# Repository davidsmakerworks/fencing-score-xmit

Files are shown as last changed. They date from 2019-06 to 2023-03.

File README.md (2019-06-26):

# fencing-score-xmit
Remote fencing scoring light display transmitter

This project is used to transmit the display from a fencing scoring machine to up to four remote displays, which could be wall lights or in-mask lights. A fencing scoring machine display consists of four lights from left to right: white, red, green, white. The red light indicates a valid hit by the fencer on the left and the green light indicates a valid hit by the fencer on the right. The corresponding white (or yellow) lights indicate a an off-target hit or equipment malfunction for the fencer on that side.

This was designed to work with a Triplette Club Scoring machine which I reverse engineered to discover the gate on each MOSFET that drives one of the lights. Inputs to the the transmitter module are soldered to the corresponding gate on the MOSFET allowing the signal to be observed without affecting the function of the scoring machine.

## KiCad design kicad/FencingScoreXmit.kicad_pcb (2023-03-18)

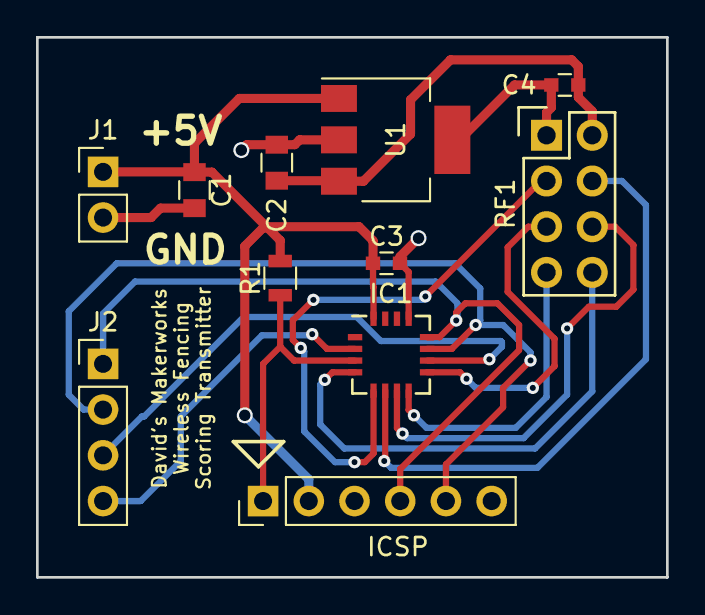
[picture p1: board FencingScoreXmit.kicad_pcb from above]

Board: 2 copper layers, 35.0 x 30.0 mm, 11 parts (0 on the bottom side), 14 nets.

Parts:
C1: 10uF; C_0805
C2: 1uF; C_0805
C3, C4: 0.1uF; C_0603
IC1: PIC16F18323-I/JQ; QFN-16-1EP_4x4mm_Pitch0.65mm
ICSP: ICSP; Pin_Header_Straight_1x06_Pitch2.54mm
J1: PWR_IN; Pin_Header_Straight_1x02_Pitch2.54mm
J2: SCORE_MACH; Pin_Header_Straight_1x04_Pitch2.54mm
R1: 10K; R_0805
RF1: nRF24L01+-MOD; nRF24L01+-Module
U1: MCP1824S33/DB; SOT-223

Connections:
+3V3: C2.1, C4.1, RF1.2, U1.3
+5V: C1.1, C3.1, IC1.16, ICSP.2, J1.1, R1.2, U1.1
GND: C1.2, C2.2, C3.2, C4.2, IC1.13, ICSP.3, J1.2, RF1.1, U1.2, U1.4
unnamed: IC1.2, J2.4
unnamed: IC1.3, ICSP.1, R1.1
unnamed: IC1.4, RF1.8
unnamed: IC1.5, RF1.3
unnamed: IC1.6, RF1.4
unnamed: IC1.7, RF1.6
unnamed: IC1.8, RF1.7
unnamed: IC1.9, RF1.5
unnamed: IC1.10, J2.3
unnamed: IC1.11, ICSP.5, J2.2
unnamed: IC1.12, ICSP.4, J2.1

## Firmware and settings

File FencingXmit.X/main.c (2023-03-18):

/*
 * Remote Fencing Score Display - Transmitter
 * Copyright (c) 2019 David Rice
 *
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
 * Designed for PIC16F18323 or PIC16F18325
 * 
 * Interfaces with nRF24L01+ 2.4 GHz RF module for transmission
 */

// PIC16F18323 Configuration Bit Settings

// 'C' source line config statements

// CONFIG1
#pragma config FEXTOSC = OFF    // FEXTOSC External Oscillator mode Selection bits (Oscillator not enabled)
#pragma config RSTOSC = HFINT1  // Power-up default value for COSC bits (HFINTOSC (1MHz))
#pragma config CLKOUTEN = OFF   // Clock Out Enable bit (CLKOUT function is disabled; I/O or oscillator function on OSC2)
#pragma config CSWEN = ON       // Clock Switch Enable bit (Writing to NOSC and NDIV is allowed)
#pragma config FCMEN = OFF      // Fail-Safe Clock Monitor Enable (Fail-Safe Clock Monitor is disabled)

// CONFIG2
#pragma config MCLRE = ON       // Master Clear Enable bit (MCLR/VPP pin function is MCLR; Weak pull-up enabled)
#pragma config PWRTE = ON       // Power-up Timer Enable bit (PWRT enabled)
#pragma config WDTE = OFF       // Watchdog Timer Enable bits (WDT disabled; SWDTEN is ignored)
#pragma config LPBOREN = OFF    // Low-power BOR enable bit (ULPBOR disabled)
#pragma config BOREN = ON       // Brown-out Reset Enable bits (Brown-out Reset enabled, SBOREN bit ignored)
#pragma config BORV = LOW       // Brown-out Reset Voltage selection bit (Brown-out voltage (Vbor) set to 2.45V)
#pragma config PPS1WAY = ON     // PPSLOCK bit One-Way Set Enable bit (The PPSLOCK bit can be cleared and set only once; PPS registers remain locked after one clear/set cycle)
#pragma config STVREN = ON      // Stack Overflow/Underflow Reset Enable bit (Stack Overflow or Underflow will cause a Reset)
#pragma config DEBUG = OFF      // Debugger enable bit (Background debugger disabled)

// CONFIG3
#pragma config WRT = OFF        // User NVM self-write protection bits (Write protection off)
#pragma config LVP = ON         // Low Voltage Programming Enable bit (Low Voltage programming enabled. MCLR/VPP pin function is MCLR. MCLRE configuration bit is ignored.)

// CONFIG4
#pragma config CP = OFF         // User NVM Program Memory Code Protection bit (User NVM code protection disabled)
#pragma config CPD = OFF        // Data NVM Memory Code Protection bit (Data NVM code protection disabled)

// #pragma config statements should precede project file includes.
// Use project enums instead of #define for ON and OFF.

#include <xc.h>
#include <stdint.h>
#include <stdbool.h>

#include "nRF24L01P.h"
#include "nRF24L01P-cfg.h"

/* CONFIGURABLE OPTIONS START HERE */
#define RF_CHANNEL      0x0CU
/* CONFIGURABLE OPTIONS END HERE */

#define _XTAL_FREQ      4000000

#define ADDR_LEN        5
#define PAYLOAD_WIDTH   1

#define LEFT_RED_MASK       0b00110000
#define RIGHT_GREEN_MASK    0b00001100
#define LEFT_WHITE_MASK     0b11000000
#define RIGHT_WHITE_MASK    0b00000011

#define LEFT_RED_ON     PORTAbits.RA0
#define RIGHT_GREEN_ON  PORTAbits.RA1
#define LEFT_WHITE_ON   PORTAbits.RA2
#define RIGHT_WHITE_ON  PORTAbits.RA4

const uint8_t strip1_addr[ADDR_LEN] = { 0x44, 0x4D, 0x57, 0x31, 0xAA };
const uint8_t strip2_addr[ADDR_LEN] = { 0x44, 0x4D, 0x57, 0x31, 0xBB };
const uint8_t mask1_addr[ADDR_LEN] = { 0x44, 0x4D, 0x57, 0x31, 0xCC };
const uint8_t mask2_addr[ADDR_LEN] = { 0x44, 0x4D, 0x57, 0x31, 0xDD };

uint8_t transfer_spi(uint8_t data) {
    SSP1BUF = data;
    
    while (!SSP1STATbits.BF);
    
    data = SSP1BUF;
    
    return data;
}

void init_ports(void) {
    /* Disable all analog features */
    ANSELA = 0x00;
    ANSELC = 0x00;
     
    /* Initialize PORTA inputs on RA0, RA1, RA2, RA4 */
    TRISA = _TRISA_TRISA0_MASK | _TRISA_TRISA1_MASK | _TRISA_TRISA2_MASK | _TRISA_TRISA4_MASK;
    
    /* Initialize all ports as outputs except RC1 (SDI) and RC5 (RF_IRQ) */
    TRISC = _TRISC_TRISC1_MASK | _TRISC_TRISC5_MASK;
    
    /* Pull all outputs low except RC3 (RF_CSN) */
    LATA = 0x00;
    LATC = _LATC_LATC3_MASK;
    
    /* Set TTL input level on RC1 (SDI1) and RC5 (RF_IRQ) */
    INLVLCbits.INLVLC1 = 0;
    INLVLCbits.INLVLC5 = 0;
}

void init_osc(void) {
    /* Set frequency of HFINTOSC to 4 MHz */
    OSCFRQbits.HFFRQ = 0b0011;
    
    /* Set clock divider to 1:1 to achieve Fosc of 4 MHz */
    OSCCON1bits.NDIV = 0b0000;
}

void init_spi(void) {
    /* Set MSSP1 to SPI Master mode, clock = Fosc / 4 = 1 MHz at Fosc = 4 MHz */
    SSP1CON1bits.SSPM = 0b0000;
    
    /* Transmit data on active-to-idle transition */
    SSP1STATbits.CKE = 1;
    
    /* Enable MSSP1 */
    SSP1CON1bits.SSPEN = 1;
}

void init_pps(void) {
    bool state;
    
    /* Preserve global interrupt state and disable interrupts */
    state = INTCONbits.GIE;
    INTCONbits.GIE = 0;
    
    /* Unlock PPS */
    PPSLOCK = 0x55;
    PPSLOCK = 0xAA;
    PPSLOCKbits.PPSLOCKED = 0;
    
    /* SCK1 on RC0 */
    RC0PPS = 0b11000;
    
    /* SDI1 on RC1 */
    SSP1DATPPS = 0b10001;
    
    /* SDO1 on RC2 */
    RC2PPS = 0b11001;
    
    /* Lock PPS */
    PPSLOCK = 0x55;
    PPSLOCK = 0xAA;
    PPSLOCKbits.PPSLOCKED = 1;
    
    /* Restore global interrupt state */
    INTCONbits.GIE = state;
}

void init_interrupts(void) {
    /* Interrupt on falling edge of external interrupt pin */
    INTCONbits.INTEDG = 0;
    
    /* Interrupt on change of scoring light pins (RA0 - RA2, RA4) */
    IOCAPbits.IOCAP0 = 1;
    IOCANbits.IOCAN0 = 1;
    
    IOCAPbits.IOCAP1 = 1;
    IOCANbits.IOCAN1 = 1;
    
    IOCAPbits.IOCAP2 = 1;
    IOCANbits.IOCAN2 = 1;
    
    IOCAPbits.IOCAP4 = 1;
    IOCANbits.IOCAN4 = 1;
    
    /* Enable IOC interrupt */
    PIE0bits.IOCIE = 1;
}

void init_rf(void) {
    /* Allow for maximum possible RF module startup time */
    __delay_ms(100);
    
    /* Set 500 uSec retry interval and 4 maximum retries */
    nrf24_write_register(NRF24_SETUP_RETR, NRF24_ARD_500 | NRF24_ARC_4);
    
    /* Set RF power to 0 dBm and data rate to 1 Mbit/Sec */
    nrf24_write_register(NRF24_RF_SETUP, NRF24_RF_PWR_0DBM);
    
    /* Set 5-byte address width */
    nrf24_write_register(NRF24_SETUP_AW, NRF24_AW_5);
    
    /* Set initial RF channel */
    nrf24_write_register(NRF24_RF_CH, RF_CHANNEL);
    
    /* Mask RX_DR interrupt on RF module, enable CRC, power up RF module in transmit-standby mode */
    nrf24_write_register(NRF24_CONFIG, NRF24_MASK_RX_DR | NRF24_EN_CRC | NRF24_PWR_UP);
    
    /* Clear any pending RF module interrupts */
    nrf24_write_register(NRF24_STATUS, NRF24_TX_DS | NRF24_MAX_RT | NRF24_RX_DR);
}

/* 
 * Sets RF module address and sends packet to specified address
 * 
 * Blocks until packet is acknowledged or until max retries are exceeded
 */
void send_packet(uint8_t *addr, uint8_t *buf, uint8_t len)
{
    nrf24_write_register_multi(NRF24_RX_ADDR_P0, addr, ADDR_LEN);
    nrf24_write_register_multi(NRF24_TX_ADDR, addr, ADDR_LEN);
    
    nrf24_flush_tx();
    nrf24_write_payload(buf, len);

    /* Strobe RF CE line to send one packet of data */
    NRF24_CE_ACTIVE();
    __delay_us(15);
    NRF24_CE_IDLE();

    while (NRF24_IRQ);

    nrf24_write_register(NRF24_STATUS, NRF24_TX_DS | NRF24_MAX_RT);
}

void main(void) {
    uint8_t buf;
    
    /* Initialize peripherals */
    init_ports();
    init_osc();
    init_spi();
    init_pps();
    init_interrupts();
    init_rf();
    
    while(1) {     
        SLEEP();
        
        IOCAF = 0x00;
        buf = 0x00;

        if (LEFT_RED_ON) {
            buf |= LEFT_RED_MASK;
        }

        if (RIGHT_GREEN_ON) {
            buf |= RIGHT_GREEN_MASK;
        }

        if (LEFT_WHITE_ON) {
            buf |= LEFT_WHITE_MASK;
        }

        if (RIGHT_WHITE_ON) {
            buf |= RIGHT_WHITE_MASK;
        }

        send_packet(strip1_addr, &buf, PAYLOAD_WIDTH);
        send_packet(strip2_addr, &buf, PAYLOAD_WIDTH);
        send_packet(mask1_addr, &buf, PAYLOAD_WIDTH);
        send_packet(mask2_addr, &buf, PAYLOAD_WIDTH);
    }
}

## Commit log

2019-06-26 Update for compatibility with restructured driver
2023-03-18 Update RF addr and silkscreen, update for KiCad 7
    [FencingScoreXmit.kicad_pcb, FencingScoreXmit.kicad_sch]
